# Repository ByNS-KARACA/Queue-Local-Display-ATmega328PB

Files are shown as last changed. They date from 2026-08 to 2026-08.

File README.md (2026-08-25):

# Queue Local Display – ATmega328PB

A modular local queue display controller designed for queue management systems used in hospitals, banks, clinics, public institutions, service counters, and similar environments.

The system is built around the **Microchip ATmega328PB** microcontroller and supports both wired **RS-485 communication** and optional **433 MHz HC-12 wireless communication**.

The display section uses cascaded **HEF4094BT shift registers**, allowing multiple large 7-segment displays to be controlled with only a few MCU pins.

## Features

* Microchip **ATmega328PB**
* 5 V MCU operation
* External **16 MHz crystal**
* 12 V DC input
* **AP63205WU-7** synchronous buck converter for 12 V to 5 V
* **MAX485** RS-485 interface
* Optional **HC-12 433 MHz wireless module**
* Independent hardware UARTs for RS-485 and HC-12
* **HEF4094BT** cascaded display architecture
* **ULN2003A** 5 V to 12 V logic interface
* Static-drive 7-segment display architecture
* 6 × large 56 mm 7-segment display positions
* 2 display positions support optional FJ11001AH alternative displays
* EEPROM-based device addressing
* SET / UP / DOWN configuration buttons
* PWM-capable global display brightness control
* External I²C expansion interface
* Additional GPIO expansion pins
* RS-485 daisy-chain capability
* Optional RS-485 termination
* Designed for continuous **24/7 operation**

## 3D Preview

### Top & Bottom Views

<p align="center">
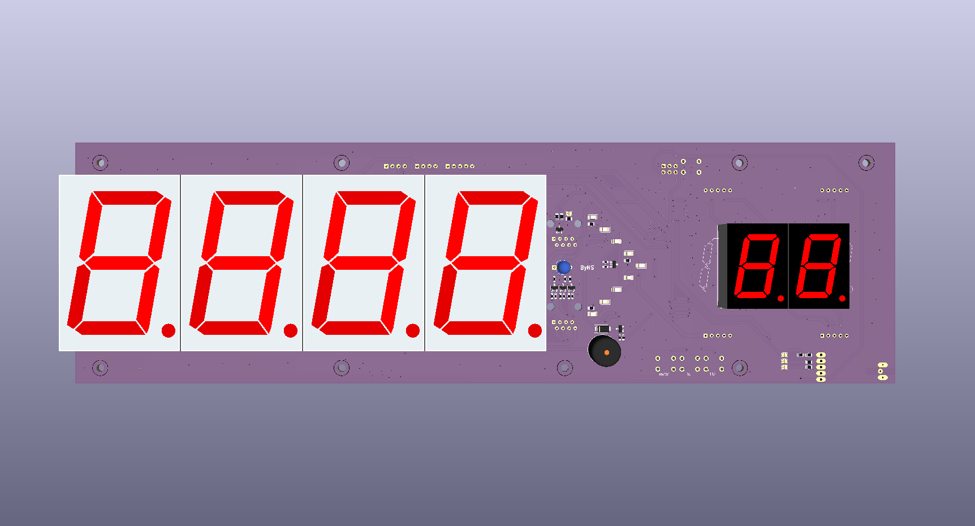
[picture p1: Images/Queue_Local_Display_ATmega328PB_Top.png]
Queue Local Display PCB Top View
  
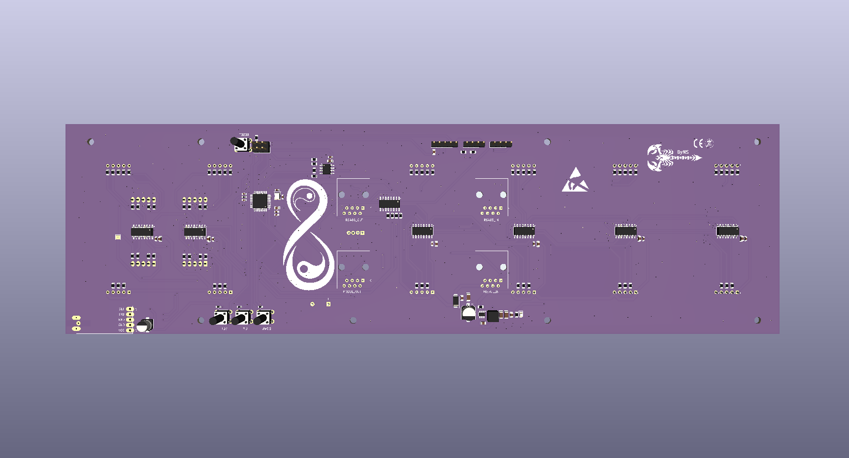
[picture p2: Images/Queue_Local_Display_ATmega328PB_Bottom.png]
Queue Local Display PCB Bottom View
  
</p>

### Angled View

<p align="center">
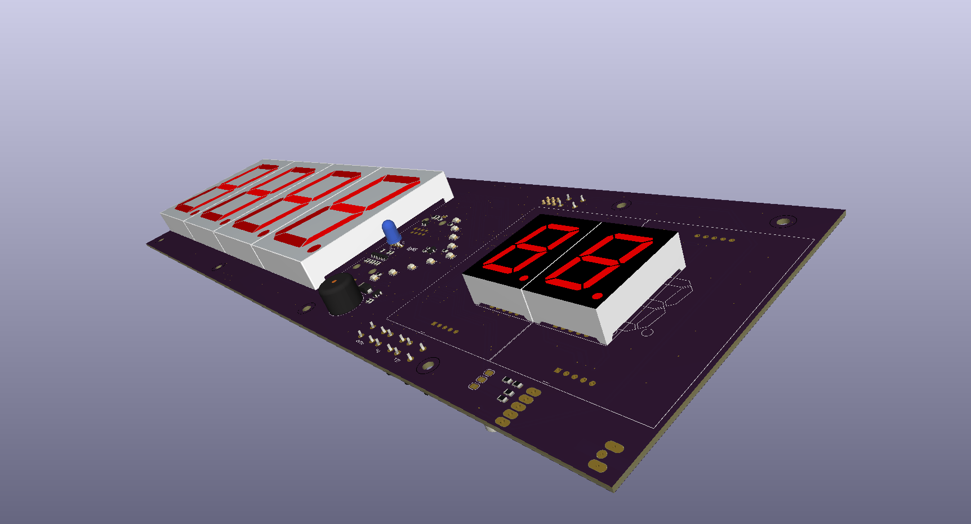
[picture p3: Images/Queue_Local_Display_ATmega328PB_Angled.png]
Queue Local Display PCB Angled View
  
</p>

## Manufacturing Files

Ready-to-manufacture Gerber and drill files are provided for this PCB.

- 📁 [Browse Gerber Files](Hardware/Gerber)
- 📦 [Download Complete Gerber ZIP](Hardware/Gerber/Queue_Local_Display_Atmega328PB_GERBER.zip)
- 🛠️ [KiCad Source Files](Hardware/KiCad)
- 📋 [Bill of Materials (BOM)](Hardware/BOM/Queue_Local_Display_ATmega328PB_BOM.xlsx)
The Gerber package includes the copper, solder mask, silkscreen, solder paste, board outline, plated-hole and non-plated-hole drill files required for PCB fabrication.

### PCB Specifications

| Parameter | Specification |
| --- | --- |
| Layers | 2 |
| PCB Thickness | 1.6 mm |
| Material | FR-4 |
| Copper Thickness | 35 µm / 1 oz |
| Board Size | approximately 340.05 × 100.05 mm |

> **Note:** Always verify the Gerber files and manufacturing parameters with your PCB manufacturer before placing an order.

## Display Configuration

The board uses:

### Main Queue Number

* 4 × **SM412301N**
* 2.3 inch / approximately 56 mm
* Red
* Common Anode
### Optional Alternative Display

Two display positions also support:

- 2 × **FJ11001AH**
- Smaller red 7-segment display
- Optional alternative to SM412301N
- Not populated simultaneously with SM412301N at the same position
### Counter / Desk Number

* 2 × **FJ11001AH**
* Red 7-segment display

Example display format:

```text
+--------------------------------+
|                                |
|       A 1 4 5       0 3        |
|                                |
|       QUEUE        COUNTER      |
+--------------------------------+
```

## Display Driver Architecture

Each 7-segment digit is controlled by its own **HEF4094BT** shift register.

The shift registers are connected in cascade:

```text
ATmega328PB
     |
     | DATA
     v
 HEF4094 #1
     |
    QS2
     v
 HEF4094 #2
     |
    QS2
     v
 HEF4094 #3
     |
    QS2
     v
 HEF4094 #4
     |
    QS2
     v
 HEF4094 #5
     |
    QS2
     v
 HEF4094 #6
```

CLOCK, STROBE and OE lines are shared between all HEF4094 devices.

The HEF4094 devices operate from the **12 V rail**.

A **ULN2003A open-collector interface** with 12 V pull-up resistors is used between the 5 V ATmega328PB and the 12 V HEF4094 control inputs.

## HEF4094 Control Pins

| Function | ATmega328PB |
| --- | --- |
| DATA | D4 |
| OE | D5 |
| CLOCK | D6 |
| STROBE | D7 |

The OE line is connected to a PWM-capable MCU output, allowing global display brightness control.

## RS-485 Interface

The board uses a **MAX485** half-duplex RS-485 transceiver.

| Function  | ATmega328PB |
| --- | --- |
| RS-485 RX | PD0 / RXD0  |
| RS-485 TX | PD1 / TXD0  |
| RE + DE | PB0 / D8 |

The RE and DE pins are connected together and controlled from a single GPIO.

The board is designed for **RS-485 bus / daisy-chain wiring**.

```text
MASTER
   |
LOCAL DISPLAY 01
   |
LOCAL DISPLAY 02
   |
LOCAL DISPLAY 03
   |
LOCAL DISPLAY 04
```

A termination resistor footprint is provided for installations where the display is located at the physical end of the RS-485 bus.

## HC-12 Wireless Interface

An optional **HC-12 433 MHz UART module** can be installed.

ATmega328PB USART1 is used for wireless communication.

| Function  | ATmega328PB |
| --- | --- |
| HC-12 RX  | PB3 / TXD1  |
| HC-12 TX  | PB4 / RXD1  |
| HC-12 SET | PB2 / D10 |

The SET input includes a pull-up resistor to keep the HC-12 in normal operating mode during startup.

## Device Address Configuration

Each local display can be assigned an individual device address.

Three buttons are used:

* **SET**
* **UP**
* **DOWN**

The selected address is stored in the internal EEPROM of the ATmega328PB.

This eliminates the need for DIP switches and simplifies installation and field configuration.

## Power Architecture

```text
12 V DC INPUT
      |
      +--------------------> Displays / HEF4094 / LEDs
      |
      +----> AP63205WU-7
                  |
                  v
                 5 V
                  |
                  +----> ATmega328PB
                  +----> MAX485
                  +----> HC-12
```

The **AP63205WU-7** provides the regulated 5 V logic supply.

The 12 V rail directly supplies the display driver section and external indicators.

## Expansion

Unused ATmega328PB GPIO pins are exposed for future expansion.

Possible future uses include:

* Status LEDs
* Additional buttons
* External sensors
* Relay outputs
* ADC inputs
* Interrupt inputs
* Additional I²C devices
* External indicators

The primary external I²C interface is:

```text
PC4 → SDA0
PC5 → SCL0
```

## Applications

* Hospital queue systems
* Bank queue systems
* Clinic waiting-room displays
* Government service counters
* Pharmacy queue systems
* Restaurant queue systems
* Reception systems
* Service desk displays

## Modular Architecture

The hardware is designed with future modular expansion in mind.

Multiple local display boards can later be combined to create a multi-row **main queue display**, while maintaining a common hardware platform.

## Project Status

**Hardware Design:** Completed
**Firmware:** In Development
**Production Validation:** Pending

This project is currently in the prototype and validation stage.

## Disclaimer

This hardware should be fully tested and validated before use in commercial, medical, industrial, or safety-critical installations.

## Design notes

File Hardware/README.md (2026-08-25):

# Hardware

This directory contains the hardware design files for the Queue Local Display.

## Contents

- KiCad schematic files
- KiCad PCB layout files
- Manufacturing files
- Schematic PDF exports
- Hardware documentation

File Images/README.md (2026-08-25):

# Images

This directory contains visual assets for the Queue Local Display project.

## Contents

- PCB 3D top view
- PCB 3D bottom view
- PCB 3D angled view
- Product and prototype images

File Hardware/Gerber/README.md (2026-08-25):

# Gerber Files

This directory contains the manufacturing output files for the Queue Local Display PCB.

## Contents

- Gerber fabrication files
- Drill files
- Optional compressed Gerber archive

These files can be used directly for PCB manufacturing.

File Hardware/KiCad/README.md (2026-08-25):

# KiCad Design Files

This directory contains the KiCad source files for the Queue Local Display hardware.

## Files

- Schematic design
- PCB layout
- KiCad project file

These files represent the editable hardware source of the project.

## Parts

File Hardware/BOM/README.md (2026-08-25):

# Bill of Materials (BOM)

This directory contains the Bill of Materials for the Queue Local Display PCB.

## Contents

- Component reference designators
- Component values
- Manufacturer part numbers
- Package / footprint information
- Quantity information
- Example supplier / LCSC part numbers where available

## Important Note

Manufacturer and supplier part numbers listed in the BOM are provided primarily as reference components.

Equivalent components with compatible electrical specifications, package dimensions, pinout, voltage/current ratings, tolerance, and temperature ratings may be used when appropriate.

Always verify component compatibility before PCB assembly.

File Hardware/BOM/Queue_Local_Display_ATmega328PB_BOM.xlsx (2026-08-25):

 | Sourced | Placed | References | Value | Footprint | Quantity | Notes
1 |  |  | C4, C6, C8, C15, C16, C18, C20, C22, C24, C26, C28, C30 | 100nF | C_0603_1608Metric | 12
2 |  |  | C5, C17, C19, C21, C23, C25, C27, C29 | 10uF | C_0805_2012Metric | 8
3 |  |  | C7, C9, C12, C14 | 100nF | C_0805_2012Metric | 4
4 |  |  | C1, C2 | 18pF, C0G/NP0 | C_0603_1608Metric | 2
5 |  |  | C10, C11 | 22uF/25V, X7R | C_1206_3216Metric | 2
6 |  |  | C3 | 47uF/35V | CP_Elec_6.3x5.4 | 1
7 |  |  | C13 | 10uF/35V, X7R | C_1206_3216Metric | 1
8 |  |  | C32 | 47uF/16V | CP_Elec_5x5.7 | 1
9 |  |  | R10, R11, R12, R13, R14, R15, R16, R18, R19, R20, R21, R22, R23, R24, R26, R27, R28, R29, R30, R31, R32, R34, R35, R36, R37, R38, R39, R40, R83, R84, R85, R86, R87, R88, R89, R91, R92, R93, R94, R95, R96, R97 | 1.2K %1 | R_0805_2012Metric | 42
10 |  |  | R17, R25, R33, R41, R42, R43, R44, R45, R46, R47, R48, R49, R50, R51, R52, R53, R54, R55, R56, R57, R90, R98 | 2.7K %1 | R_0805_2012Metric | 22
11 |  |  | R69, R70, R71, R72, R75, R78, R81, R103 | 10K | R_0603_1608Metric | 8
12 |  |  | R2, R3, R4, R5, R6, R7 | 4.7K | R_0805_2012Metric | 6
13 |  |  | R73, R74, R77, R80, R102 | 1K | R_0603_1608Metric | 5
14 |  |  | R1, R60, R61, R68 | 10K | R_0805_2012Metric | 4
15 |  |  | R65, R66, R67 | 33 | R_0805_2012Metric | 3
16 |  |  | R76, R79, R82 | 220 | R_0603_1608Metric | 3
17 |  |  | R99, R100, R101 | 470 | R_0805_2012Metric | 3
18 |  |  | R8, R9 | 1K | R_0805_2012Metric | 2
19 |  |  | R58, R59 | 220 | R_0805_2012Metric | 2
20 |  |  | R62, R63 | 10 | R_0805_2012Metric | 2
21 |  |  | R64 | 120 | R_0805_2012Metric | 1
22 |  |  | L1 | 10uH | L_0603_1608Metric | 1
23 | C341032 |  | L2 | 4.7uH 3A 5*5mm , YNR5040-4R7M | L_Chilisin_BWVS00505040 | 1
24 |  | GREEN_LED | D5, D7, D8, D9, D10, D11, D12, D13, D14 | GREEN_LED | LED_1206_3216Metric | 9
25 |  |  | D1 | RED_LED | LED_0805_2012Metric | 1
26 |  |  | D2 | SS34 | D_SMA | 1
27 |  |  | D3 | SM712_SOT23 | SOT-23 | 1
28 |  |  | D4 | M7F | D_SMA | 1
29 | XL-B504RGBC | CA_RGB_LED | D6 | LED_BAGR | LED_D5.0mm-4_RGB_Wide_Pins | 1
30 | C7868 |  | U2, U5, U6, U7, U8, U9 | HEF4094BT,653 | SOIC-16_3.9x9.9mm_P1.27mm | 6
31 | C164872 |  | U10, U11, U12, U13, U15, U16 | SM412301N | SA15-11xxx | 6 | Default display option. Six SM412301N displays are listed. Two of these display positions may alternatively use FJ11001AH.
32 | C461612 | ATMEGA328PB | U1 | ATmega328PB-A | TQFP-32_7x7mm_P0.8mm | 1
33 | C5181464 |  | U3 | ULN2003A | SOIC-16_3.9x9.9mm_P1.27mm | 1
34 |  |  | U4 | AP63205WU-7 | TSOT-23-6 | 1
35 |  |  | U14 | MAX485ED | SOIC-8_3.9x4.9mm_P1.27mm | 1
36 | C12668 |  | Y1 | 16Mhz, 12pF | Crystal_SMD_3225-4Pin_3.2x2.5mm | 1
37 |  |  | SW1 | SW_Push | SW_PUSH_6mm_H13mm | 1
38 |  |  | SW2 | UP | SW_PUSH_6mm_H13mm | 1
39 |  |  | SW3 | DOWN | SW_PUSH_6mm_H13mm | 1
40 |  |  | SW4 | SET | SW_PUSH_6mm_H13mm | 1
41 |  |  | Q1, Q2, Q3, Q4, Q5 | MMBT2222A | SOT-23 | 5
42 | C10687 |  | AFF1, AFF2 | FJ11001AH | 7SegmentLED_LTS6760_LTS6780 | 2 | OPTIONAL ALTERNATIVE / DNP by default. FJ11001AH can replace two SM412301N display positions. Do not populate both display types at the same position.
43 |  |  | BZ1 | Buzzer | Buzzer_12x9.5RM7.6 | 1
44 |  |  | M1 | HC-12 | MA05-1 | 1
45 |  |  | TP1 | TestPoint | TestPoint_Pad_2.0x2.0mm | 1
46 |  |  | J2, J4, J7, J8 | RJ45 | RJ45_Amphenol_54602-x08_Horizontal | 4
47 |  |  | J1 | AVR-ISP | PinHeader_2x03_P2.54mm_Vertical | 1
48 |  |  | J3 | UART-SERIAL | PinHeader_1x05_P2.54mm_Vertical | 1
49 |  |  | J5 | I2C | PinHeader_1x04_P2.54mm_Vertical | 1
50 |  |  | J6 | NULL_PIN | PinHeader_1x04_P2.54mm_Vertical | 1
 |  | NOTE-1 | Orange-colored companents will be supplied but will not be mounted on the board.
 |  | NOTE-2 | Red-colored companents will not be supplied and will not be mounted on the board.
 |  | NOTE-3 | **COMPONENT SELECTION NOTE** The manufacturer part numbers listed in this BOM are provided for reference only and do not mandate the use of those exact components. The manufacturer may select suitable and readily available equivalent components, provided that they fully meet or exceed the specified electrical, mechanical, functional, quality, and reliability requirements. Any proposed alternative must be compatible in terms of package, footprint, pinout, operating ratings, temperature range, and applicable certifications. All substitutions must be submitted for approval before procurement or production.
 |  | NOTE-4 | **DISPLAY OPTION NOTE** The standard configuration uses 6 × SM412301N displays. For two display positions, FJ11001AH may be used as an optional alternative instead of SM412301N. These alternatives are mutually exclusive at the same position; do not populate both display types simultaneously.

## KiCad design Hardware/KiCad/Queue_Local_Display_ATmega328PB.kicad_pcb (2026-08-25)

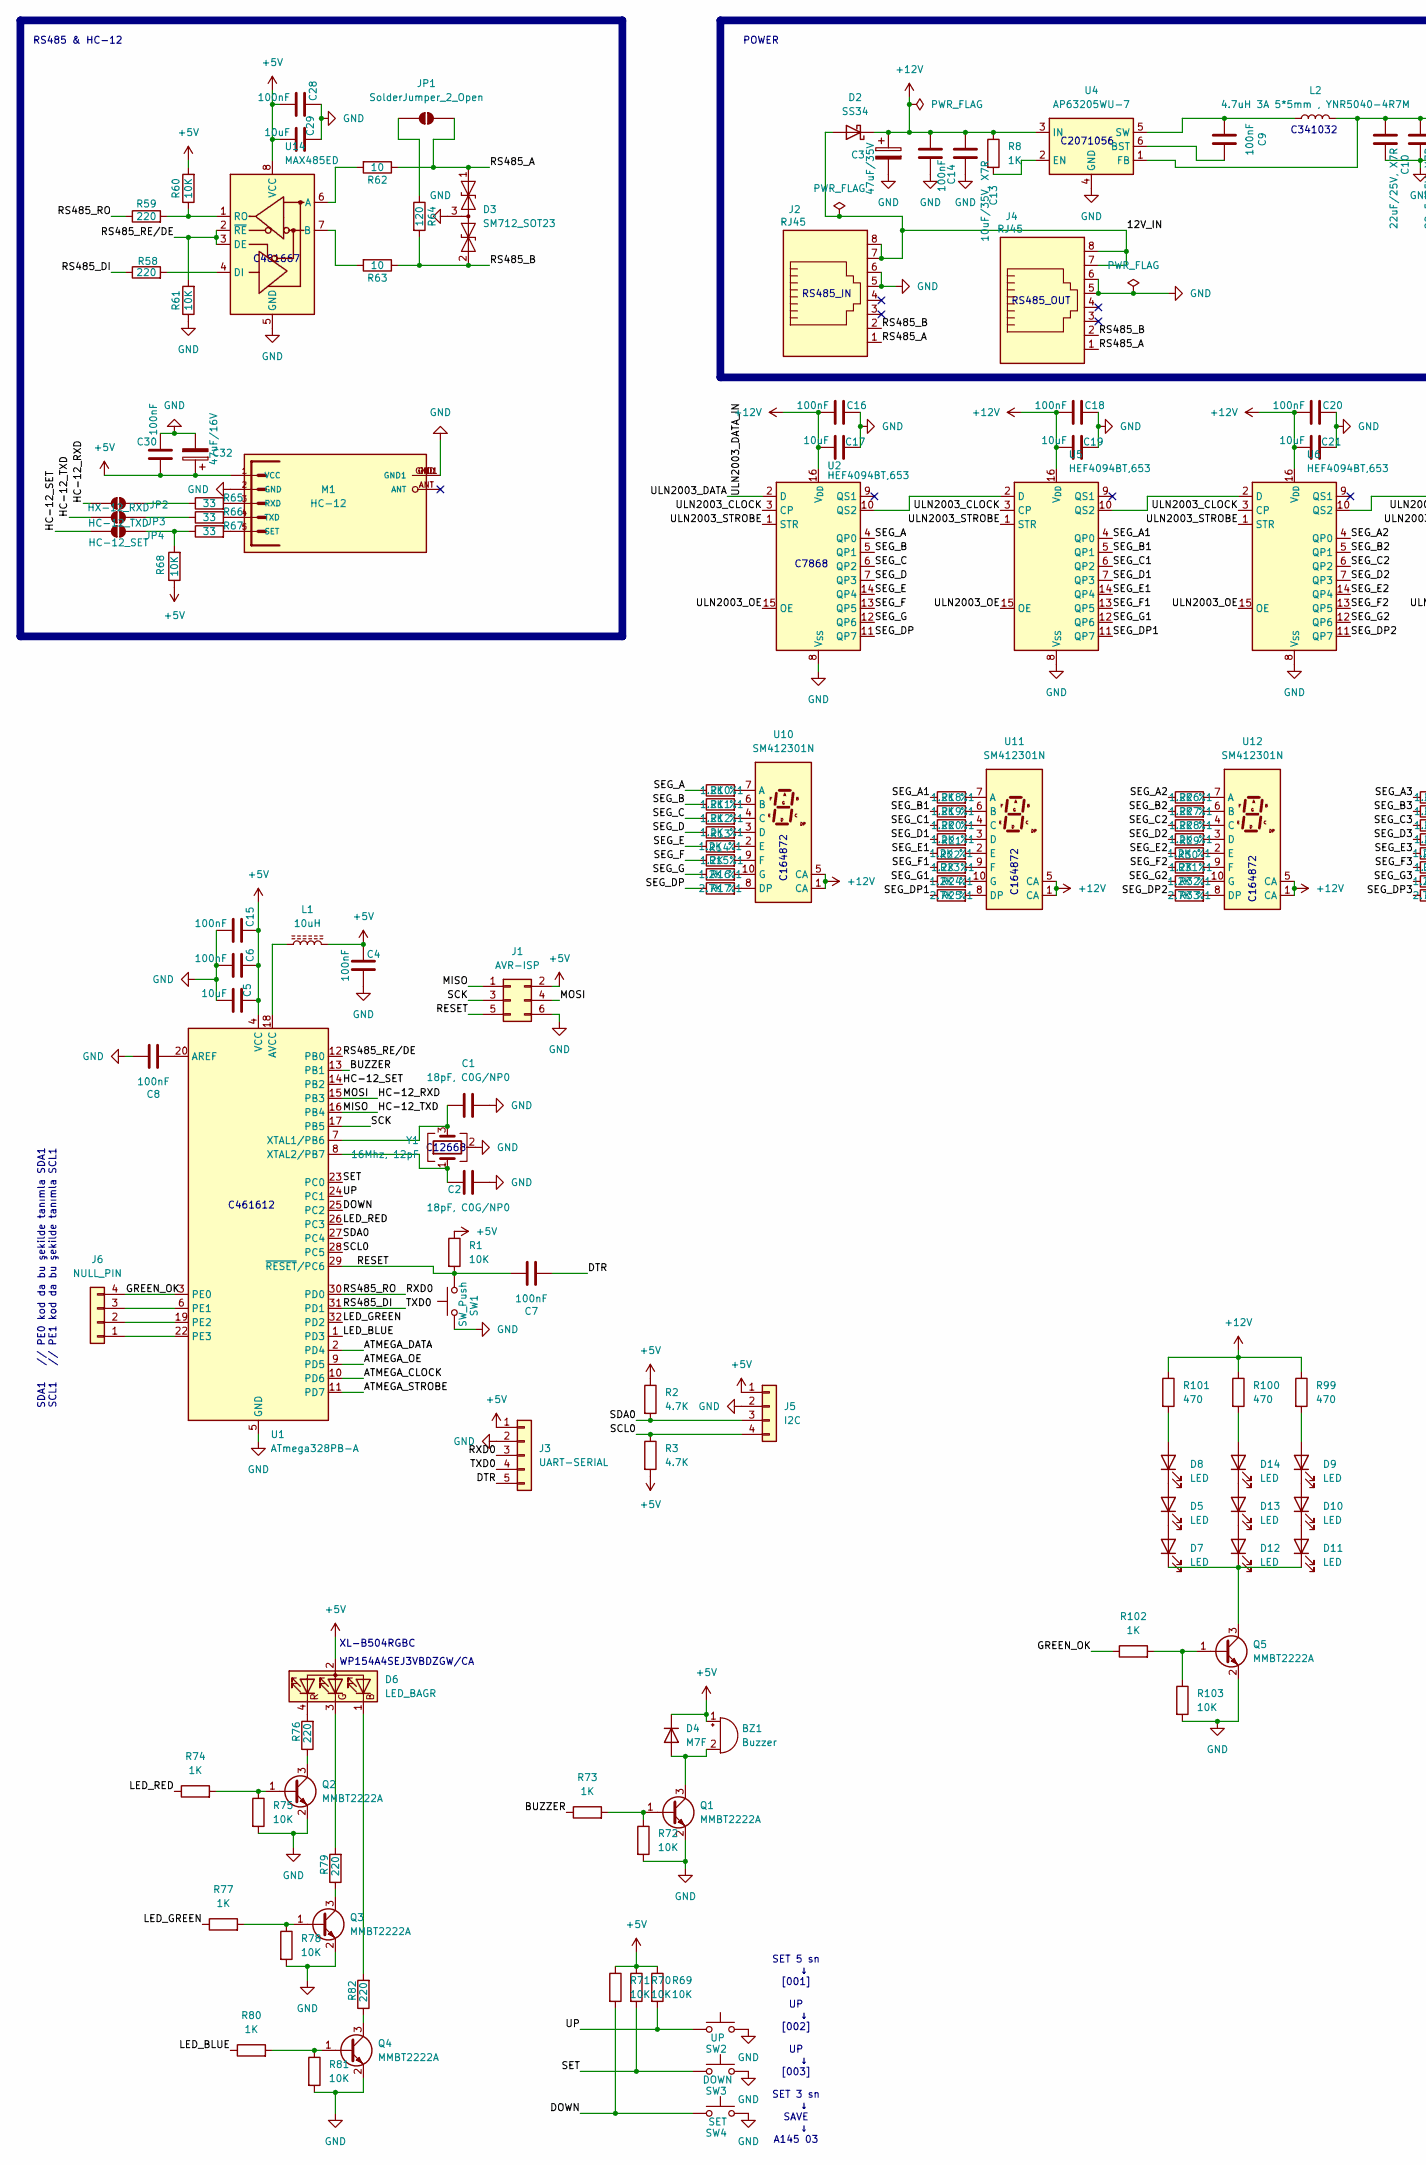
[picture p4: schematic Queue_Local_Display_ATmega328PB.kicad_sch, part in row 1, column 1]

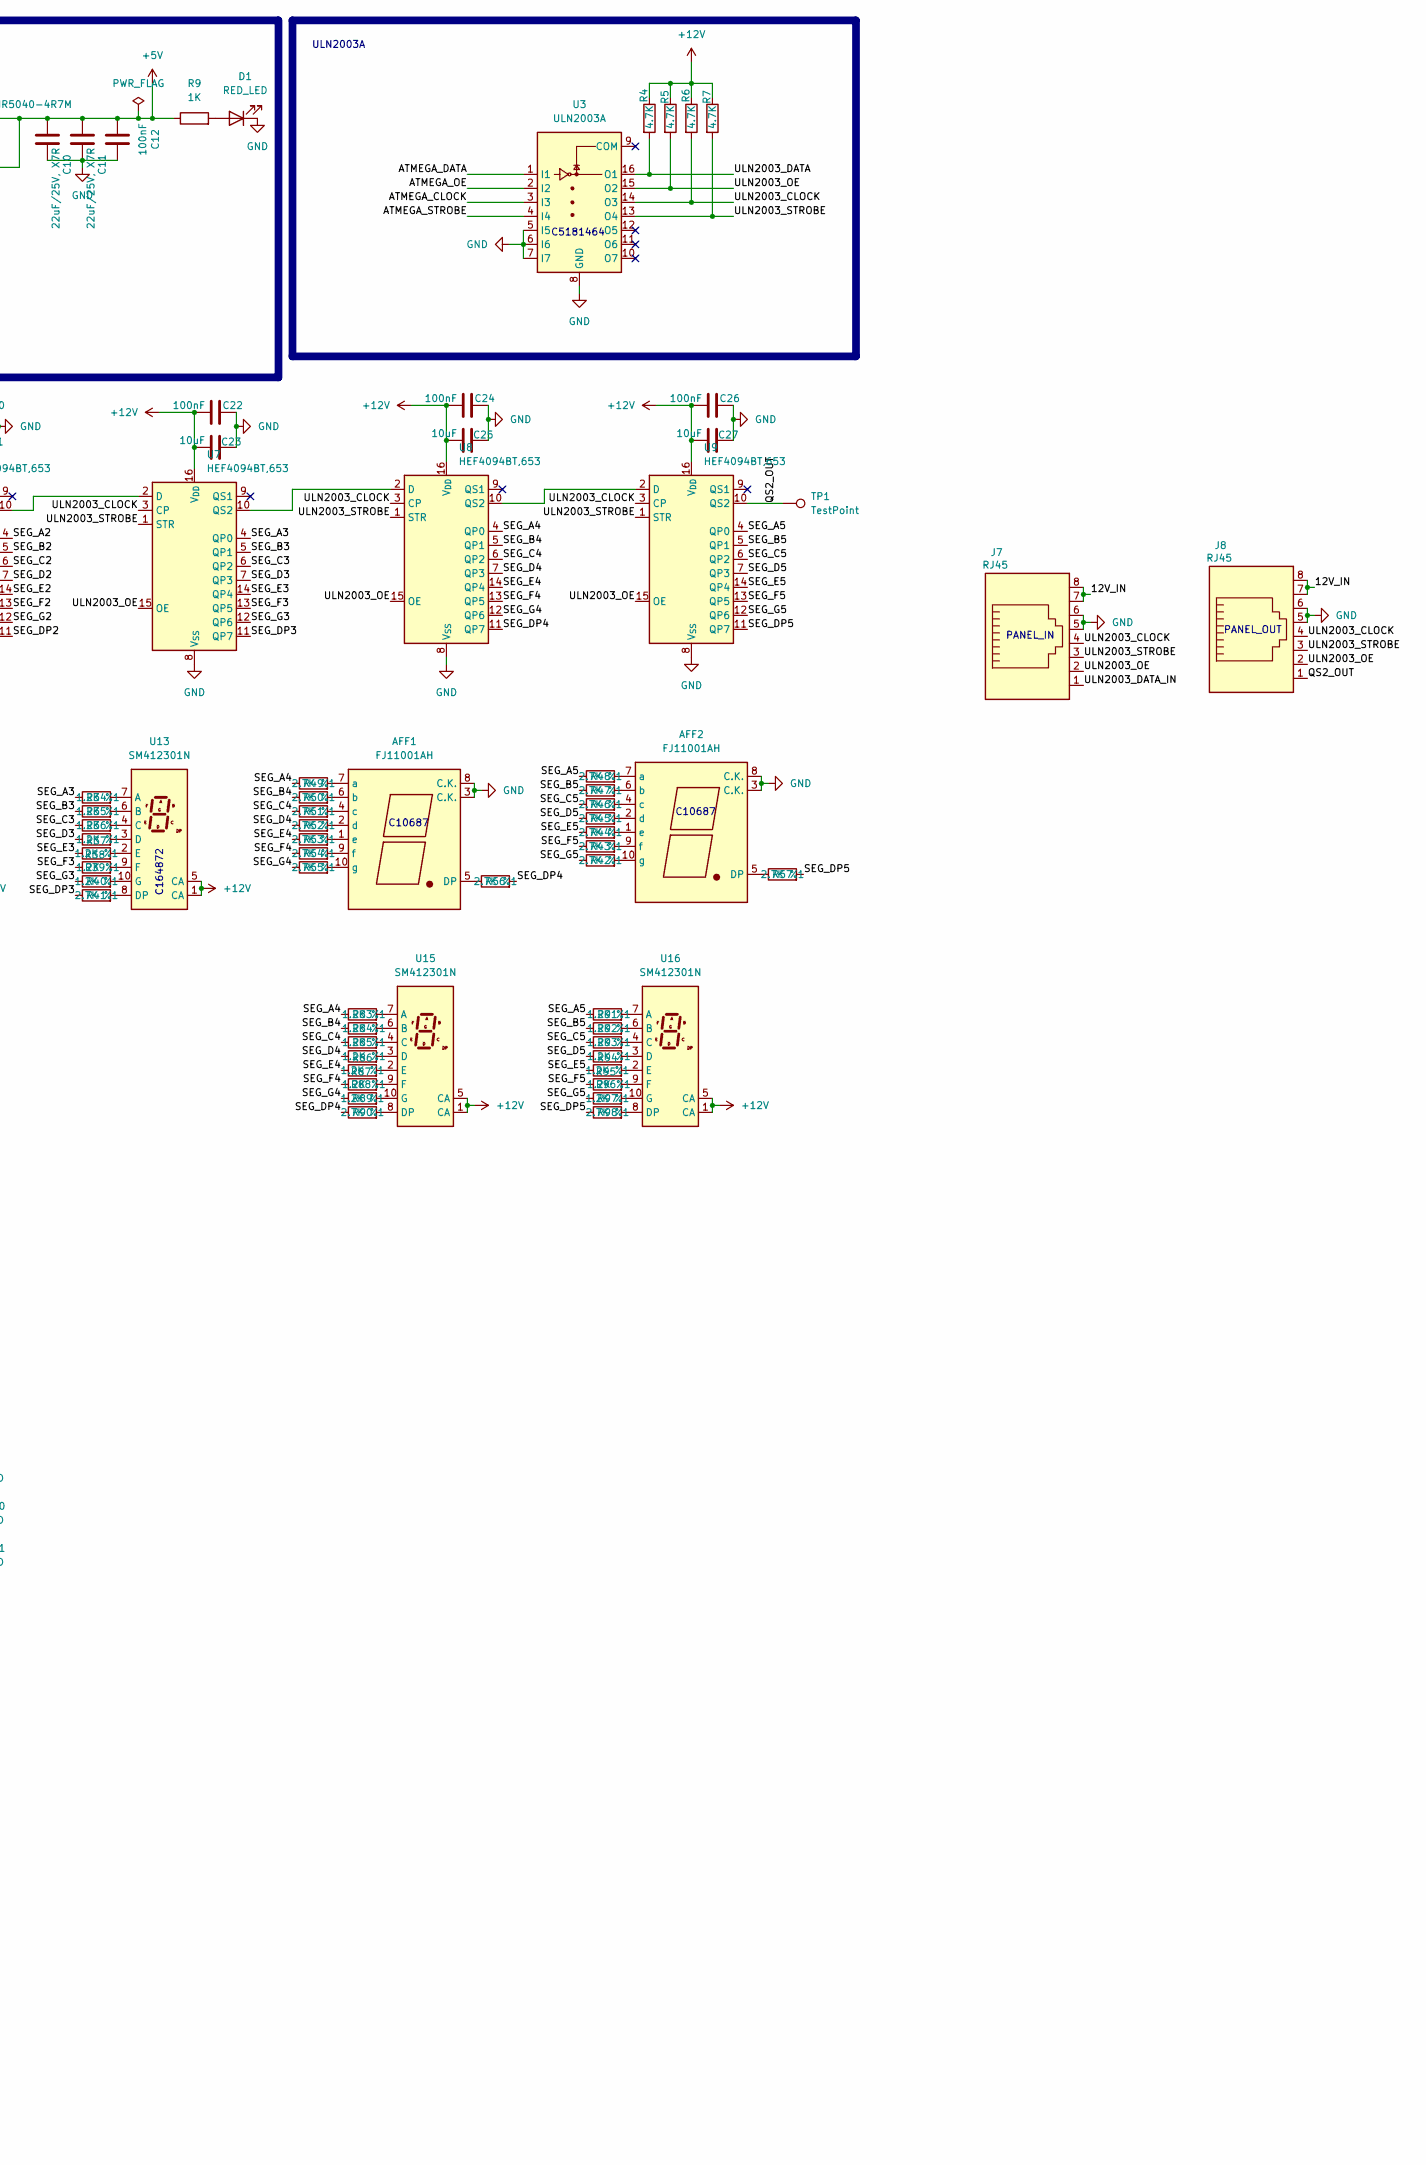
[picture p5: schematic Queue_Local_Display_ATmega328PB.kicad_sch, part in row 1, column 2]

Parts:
AFF1, AFF2: FJ11001AH; 7SegmentLED_LTS6760_LTS6780
BZ1: Buzzer; Buzzer_12x9.5RM7.6
C1, C2: 18pF, C0G/NP0; C_0603_1608Metric
C3: 47uF/35V; CP_Elec_6.3x5.4
C4, C6, C8, C15, C16, C18, C20, C22, C24, C26, C28, C30: 100nF; C_0603_1608Metric
C5, C17, C19, C21, C23, C25, C27, C29: 10uF; C_0805_2012Metric
C7, C9, C12, C14: 100nF; C_0805_2012Metric
C10, C11: 22uF/25V, X7R; C_1206_3216Metric
C13: 10uF/35V, X7R; C_1206_3216Metric
C32: 47uF/16V; CP_Elec_5x5.7
D1: RED_LED; LED_0805_2012Metric
D2: SS34; D_SMA
D3: SM712_SOT23; SOT-23
D4: M7F; D_SMA
D5, D7, D8, D9, D10, D11, D12, D13, D14: LED; LED_1206_3216Metric
D6: LED_BAGR; LED_D5.0mm-4_RGB_Wide_Pins
J1: AVR-ISP; PinHeader_2x03_P2.54mm_Vertical
J2, J4, J7, J8: RJ45; RJ45_Amphenol_54602-x08_Horizontal
J3: UART-SERIAL; PinHeader_1x05_P2.54mm_Vertical
J5: I2C; PinHeader_1x04_P2.54mm_Vertical
J6: NULL_PIN; PinHeader_1x04_P2.54mm_Vertical
JP1: SolderJumper_2_Open; SolderJumper-2_P1.3mm_Open_RoundedPad1.0x1.5mm
JP2: HX-12_RXD; SolderJumper-2_P1.3mm_Open_RoundedPad1.0x1.5mm
JP3: HC-12_TXD; SolderJumper-2_P1.3mm_Open_RoundedPad1.0x1.5mm
JP4: HC-12_SET; SolderJumper-2_P1.3mm_Open_RoundedPad1.0x1.5mm
L1: 10uH; L_0603_1608Metric
L2: 4.7uH 3A 5*5mm , YNR5040-4R7M; L_Chilisin_BWVS00505040
M1: HC-12; MA05-1
Q1, Q2, Q3, Q4, Q5: MMBT2222A; SOT-23
R1, R60, R61, R68: 10K; R_0805_2012Metric
R2, R3, R4, R5, R6, R7: 4.7K; R_0805_2012Metric
R8, R9: 1K; R_0805_2012Metric
R10, R11, R12, R13, R14, R15, R16, R18, R19, R20, R21, R22, R23, R24, R26, R27, R28, R29, R30, R31, R32, R34, R35, R36, R37, R38, R39, R40, R83, R84, R85, R86, R87, R88, R89, R91, R92, R93, R94, R95, R96, R97: 1.2K %1; R_0805_2012Metric
R17, R25, R33, R41, R42, R43, R44, R45, R46, R47, R48, R49, R50, R51, R52, R53, R54, R55, R56, R57, R90, R98: 2.7K %1; R_0805_2012Metric
R58, R59: 220; R_0805_2012Metric
R62, R63: 10; R_0805_2012Metric
R64: 120; R_0805_2012Metric
R65, R66, R67: 33; R_0805_2012Metric
R69, R70, R71, R72, R75, R78, R81, R103: 10K; R_0603_1608Metric
R73, R74, R77, R80, R102: 1K; R_0603_1608Metric
R76, R79, R82: 220; R_0603_1608Metric
R99, R100, R101: 470; R_0805_2012Metric
SW1: SW_Push; SW_PUSH_6mm_H13mm
SW2: UP; SW_PUSH_6mm_H13mm
SW3: DOWN; SW_PUSH_6mm_H13mm
SW4: SET; SW_PUSH_6mm_H13mm
TP1: TestPoint; TestPoint_Pad_2.0x2.0mm
U1: ATmega328PB-A; TQFP-32_7x7mm_P0.8mm
U2, U5, U6, U7, U8, U9: HEF4094BT,653; SOIC-16_3.9x9.9mm_P1.27mm
U3: ULN2003A; SOIC-16_3.9x9.9mm_P1.27mm
U4: AP63205WU-7; TSOT-23-6
U10, U11, U12, U13, U15, U16: SM412301N; SA15-11xxx
U14: MAX485ED; SOIC-8_3.9x4.9mm_P1.27mm
Y1: 16Mhz, 12pF; Crystal_SMD_3225-4Pin_3.2x2.5mm

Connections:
+5V: BZ1.1 (+), C4.1, C5.2, C6.2, C10.1, C11.1, C12.1, C15.2, C28.1, C29.1, C30.1, C32.1, D4.1 (K), D6.2 (A), J1.2, J3.1, J5.1, L1.2, L2.2, M1.1 (VCC), R1.1, R2.1, R3.2, R9.1, R60.2, R68.1, R69.1, R70.1, R71.1, U1.4 (VCC), U4.1 (FB), U14.8 (VCC)
+12V: C3.1, C13.1, C14.1, C16.1, C17.1, C18.1, C19.1, C20.1, C21.1, C22.1, C23.1, C24.1, C25.1, C26.1, C27.1, D2.1 (K), R4.1, R5.1, R6.1, R7.1, R8.1, R99.1, R100.1, R101.1, U2.16 (V_{DD}), U4.3 (IN), U5.16 (V_{DD}), U6.16 (V_{DD}), U7.16 (V_{DD}), U8.16 (V_{DD}), U9.16 (V_{DD}), U10.1 (CA), U10.5 (CA), U11.1 (CA), U11.5 (CA), U12.1 (CA), U12.5 (CA), U13.1 (CA), U13.5 (CA), U15.1 (CA), U15.5 (CA), U16.1 (CA), U16.5 (CA)
/12V_IN: D2.2 (A), J2.7, J2.8, J4.7, J4.8, J7.7, J7.8, J8.7, J8.8
/ATMEGA_CLOCK: U1.10 (PD6), U3.3 (I3)
/ATMEGA_DATA: U1.2 (PD4), U3.1 (I1)
/ATMEGA_OE: U1.9 (PD5), U3.2 (I2)
/ATMEGA_STROBE: U1.11 (PD7), U3.4 (I4)
/BUZZER: R73.1, U1.13 (PB1)
/DTR: C7.1, J3.5
/GREEN_OK: J6.4, R102.1, U1.3 (PE0)
/HC-12_RXD: J1.4, JP2.1 (A), U1.15 (PB3)
/HC-12_SET: JP4.1 (A), U1.14 (PB2)
/HC-12_TXD: J1.1, JP3.1 (A), U1.16 (PB4)
/LED_BLUE: R80.1, U1.1 (PD3)
/LED_GREEN: R77.1, U1.32 (PD2)
/LED_RED: R74.1, U1.26 (PC3)
/QS2_OUT: J8.1, TP1.1 (1_1), U9.10 (QS2)
/RESET: C7.2, J1.5, R1.2, SW1.2, U1.29 (~RESET/PC6)
/RS485_A: D3.1 (A1), J2.1, J4.1, JP1.2 (B), R62.1
/RS485_B: D3.2 (A2), J2.2, J4.2, R63.1, R64.2
/RS485_DI: J3.4, R58.1, U1.31 (PD1)
/RS485_RE/DE: R61.2, U1.12 (PB0), U14.2 (~RE), U14.3 (DE)
/RS485_RO: J3.3, R59.1, U1.30 (PD0)
/SCK: J1.3, U1.17 (PB5)
/SCL0: J5.4, R3.1, U1.28 (PC5)
/SDA0: J5.3, R2.2, U1.27 (PC4)
/SEG_A: R10.1, U2.4 (QP0)
/SEG_A1: R18.1, U5.4 (QP0)
/SEG_A2: R26.1, U6.4 (QP0)
/SEG_A3: R34.1, U7.4 (QP0)
/SEG_A4: R49.1, R83.1, U8.4 (QP0)
/SEG_A5: R48.1, R91.1, U9.4 (QP0)
/SEG_B: R11.1, U2.5 (QP1)
/SEG_B1: R19.1, U5.5 (QP1)
/SEG_B2: R27.1, U6.5 (QP1)
/SEG_B3: R35.1, U7.5 (QP1)
/SEG_B4: R50.1, R84.1, U8.5 (QP1)
/SEG_B5: R47.1, R92.1, U9.5 (QP1)
/SEG_C: R12.1, U2.6 (QP2)
/SEG_C1: R20.1, U5.6 (QP2)
/SEG_C2: R28.1, U6.6 (QP2)
/SEG_C3: R36.1, U7.6 (QP2)
/SEG_C4: R51.1, R85.1, U8.6 (QP2)
/SEG_C5: R46.1, R93.1, U9.6 (QP2)
/SEG_D: R13.1, U2.7 (QP3)
/SEG_D1: R21.1, U5.7 (QP3)
/SEG_D2: R29.1, U6.7 (QP3)
/SEG_D3: R37.1, U7.7 (QP3)
/SEG_D4: R52.1, R86.1, U8.7 (QP3)
/SEG_D5: R45.1, R94.1, U9.7 (QP3)
/SEG_DP: R17.1, U2.11 (QP7)
/SEG_DP1: R25.1, U5.11 (QP7)
/SEG_DP2: R33.1, U6.11 (QP7)
/SEG_DP3: R41.1, U7.11 (QP7)
/SEG_DP4: R56.2, R90.1, U8.11 (QP7)
/SEG_DP5: R57.2, R98.1, U9.11 (QP7)
/SEG_E: R14.1, U2.14 (QP4)
/SEG_E1: R22.1, U5.14 (QP4)
/SEG_E2: R30.1, U6.14 (QP4)
/SEG_E3: R38.1, U7.14 (QP4)
/SEG_E4: R53.1, R87.1, U8.14 (QP4)
/SEG_E5: R44.1, R95.1, U9.14 (QP4)
/SEG_F: R15.1, U2.13 (QP5)
/SEG_F1: R23.1, U5.13 (QP5)
/SEG_F2: R31.1, U6.13 (QP5)
/SEG_F3: R39.1, U7.13 (QP5)
/SEG_F4: R54.1, R88.1, U8.13 (QP5)
/SEG_F5: R43.1, R96.1, U9.13 (QP5)
/SEG_G: R16.1, U2.12 (QP6)
/SEG_G1: R24.1, U5.12 (QP6)
/SEG_G2: R32.1, U6.12 (QP6)
/SEG_G3: R40.1, U7.12 (QP6)
/SEG_G4: R55.1, R89.1, U8.12 (QP6)
/SEG_G5: R42.1, R97.1, U9.12 (QP6)
/ULN2003_CLOCK: J7.4, J8.4, R6.2, U2.3 (CP), U3.14 (O3), U5.3 (CP), U6.3 (CP), U7.3 (CP), U8.3 (CP), U9.3 (CP)
/ULN2003_DATA: J7.1, R4.2, U2.2 (D), U3.16 (O1)
/ULN2003_OE: J7.2, J8.2, R5.2, U2.15 (OE), U3.15 (O2), U5.15 (OE), U6.15 (OE), U7.15 (OE), U8.15 (OE), U9.15 (OE)
/ULN2003_STROBE: J7.3, J8.3, R7.2, U2.1 (STR), U3.13 (O4), U5.1 (STR), U6.1 (STR), U7.1 (STR), U8.1 (STR), U9.1 (STR)
/UP: R69.2, SW2.1, U1.24 (PC1)
GND: AFF1.3 (C.K.), AFF1.8 (C.K.), AFF2.3 (C.K.), AFF2.8 (C.K.), C1.2, C2.1, C3.2, C4.2, C5.1, C6.1, C8.2, C10.2, C11.2, C12.2, C13.2, C14.2, C15.1, C16.2, C17.2, C18.2, C19.2, C20.2, C21.2, C22.2, C23.2, C24.2, C25.2, C26.2, C27.2, C28.2, C29.2, C30.2, C32.2, D1.1 (K), D3.3 (common), J1.6, J2.5, J2.6, J3.2, J4.5, J4.6, J5.2, J7.5, J7.6, J8.5, J8.6, M1.2 (GND), M1.GND (GND1), M1.GND1, Q1.2 (E), Q2.2 (E), Q3.2 (E), Q4.2 (E), Q5.2 (E), R61.1, R72.2, R75.2, R78.2, R81.2, R103.2, SW1.1, SW2.2, SW3.2, SW4.2, U1.5 (GND), U1.21 (GND), U2.8 (V_{SS}), U3.5 (I5), U3.6 (I6), U3.7 (I7), U3.8 (GND), U4.4 (GND), U5.8 (V_{SS}), U6.8 (V_{SS}), U7.8 (V_{SS}), U8.8 (V_{SS}), U9.8 (V_{SS}), U14.5 (GND), Y1.2 (G), Y1.4 (G)
unnamed: AFF1.5 (DP), R56.1
unnamed: AFF1.7 (a), R49.2
unnamed: AFF1.6 (b), R50.2
unnamed: AFF1.4 (c), R51.2
unnamed: AFF1.2 (d), R52.2
unnamed: AFF1.1 (e), R53.2
unnamed: AFF1.9 (f), R54.2
unnamed: AFF1.10 (g), R55.2
unnamed: AFF2.5 (DP), R57.1
unnamed: AFF2.7 (a), R48.2
unnamed: AFF2.6 (b), R47.2
unnamed: AFF2.4 (c), R46.2
unnamed: AFF2.2 (d), R45.2
unnamed: AFF2.1 (e), R44.2
unnamed: AFF2.9 (f), R43.2
unnamed: AFF2.10 (g), R42.2
unnamed: BZ1.2 (-), D4.2 (A), Q1.3 (C)
unnamed: D1.2 (A), R9.2
unnamed: D5.2 (A), D8.1 (K)
unnamed: D5.1 (K), D7.2 (A)
unnamed: D6.1 (BK), R82.2
unnamed: D6.3 (GK), R79.2
unnamed: D6.4 (RK), R76.2
unnamed: D8.2 (A), R101.2
unnamed: D9.2 (A), R99.2
unnamed: D9.1 (K), D10.2 (A)
unnamed: D10.1 (K), D11.2 (A)
unnamed: D7.1 (K), D11.1 (K), D12.1 (K), Q5.3 (C)
unnamed: D12.2 (A), D13.1 (K)
unnamed: D13.2 (A), D14.1 (K)
unnamed: D14.2 (A), R100.2
unnamed: J6.1, U1.22 (PE3)
unnamed: J6.2, U1.19 (PE2)
unnamed: J6.3, U1.6 (PE1)
unnamed: JP1.1 (A), R64.1
unnamed: JP2.2 (B), R65.1
unnamed: JP3.2 (B), R66.1
unnamed: JP4.2 (B), R67.1, R68.2
unnamed: M1.3 (RXD), R65.2
unnamed: M1.5 (SET), R67.2
unnamed: M1.4 (TXD), R66.2
unnamed: Q1.1 (B), R72.1, R73.2
unnamed: Q2.1 (B), R74.2, R75.1
unnamed: Q2.3 (C), R76.1
unnamed: Q3.1 (B), R77.2, R78.1
unnamed: Q3.3 (C), R79.1
unnamed: Q4.1 (B), R80.2, R81.1
unnamed: Q4.3 (C), R82.1
unnamed: Q5.1 (B), R102.2, R103.1
unnamed: C8.1, U1.20 (AREF)
unnamed: L1.1, U1.18 (AVCC)
unnamed: C1.1, U1.7 (XTAL1/PB6), Y1.3
unnamed: C2.2, U1.8 (XTAL2/PB7), Y1.1
unnamed: U2.10 (QS2), U5.2 (D)
unnamed: C9.2, U4.6 (BST)
unnamed: R8.2, U4.2 (EN)
unnamed: C9.1, L2.1, U4.5 (SW)
unnamed: U5.10 (QS2), U6.2 (D)
unnamed: U6.10 (QS2), U7.2 (D)
unnamed: U7.10 (QS2), U8.2 (D)
unnamed: U8.10 (QS2), U9.2 (D)
unnamed: R10.2, U10.7 (A)
unnamed: R11.2, U10.6 (B)
unnamed: R12.2, U10.4 (C)
unnamed: R13.2, U10.3 (D)
unnamed: R17.2, U10.8 (DP)
unnamed: R14.2, U10.2 (E)
unnamed: R15.2, U10.9 (F)
unnamed: R16.2, U10.10 (G)
unnamed: R18.2, U11.7 (A)
unnamed: R19.2, U11.6 (B)
unnamed: R20.2, U11.4 (C)
unnamed: R21.2, U11.3 (D)
unnamed: R25.2, U11.8 (DP)
unnamed: R22.2, U11.2 (E)
unnamed: R23.2, U11.9 (F)
unnamed: R24.2, U11.10 (G)
unnamed: R26.2, U12.7 (A)
unnamed: R27.2, U12.6 (B)
unnamed: R28.2, U12.4 (C)
unnamed: R29.2, U12.3 (D)
unnamed: R33.2, U12.8 (DP)
unnamed: R30.2, U12.2 (E)
unnamed: R31.2, U12.9 (F)
unnamed: R32.2, U12.10 (G)
unnamed: R34.2, U13.7 (A)
unnamed: R35.2, U13.6 (B)
unnamed: R36.2, U13.4 (C)
unnamed: R37.2, U13.3 (D)
unnamed: R41.2, U13.8 (DP)
unnamed: R38.2, U13.2 (E)
unnamed: R39.2, U13.9 (F)
unnamed: R40.2, U13.10 (G)
unnamed: R62.2, U14.6 (A)
unnamed: R63.2, U14.7 (B)
unnamed: R58.2, U14.4 (DI)
unnamed: R59.2, R60.1, U14.1 (RO)
unnamed: R83.2, U15.7 (A)
unnamed: R84.2, U15.6 (B)
unnamed: R85.2, U15.4 (C)
unnamed: R86.2, U15.3 (D)
unnamed: R90.2, U15.8 (DP)
unnamed: R87.2, U15.2 (E)
unnamed: R88.2, U15.9 (F)
unnamed: R89.2, U15.10 (G)
unnamed: R91.2, U16.7 (A)
unnamed: R92.2, U16.6 (B)
unnamed: R93.2, U16.4 (C)
unnamed: R94.2, U16.3 (D)
unnamed: R98.2, U16.8 (DP)
unnamed: R95.2, U16.2 (E)
unnamed: R96.2, U16.9 (F)
unnamed: R97.2, U16.10 (G)

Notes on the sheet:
XL-B504RGBC
ULN2003A
C341032
RS485_IN
C164872
RS485 & HC-12
C5181464
C481667
C461612
SET 5 sn ↓ [001] UP ↓ [002] UP ↓ [003] SET 3 sn ↓ SAVE ↓ A145 03
C12668
RS485_OUT
POWER
C10687
SDA1 // PE0 kod da bu şekilde tanımla SDA1 SCL1 // PE1 kod da bu şekilde tanımla SCL1
C7868
PANEL_OUT
C2071056
PANEL_IN
WP154A4SEJ3VBDZGW/CA

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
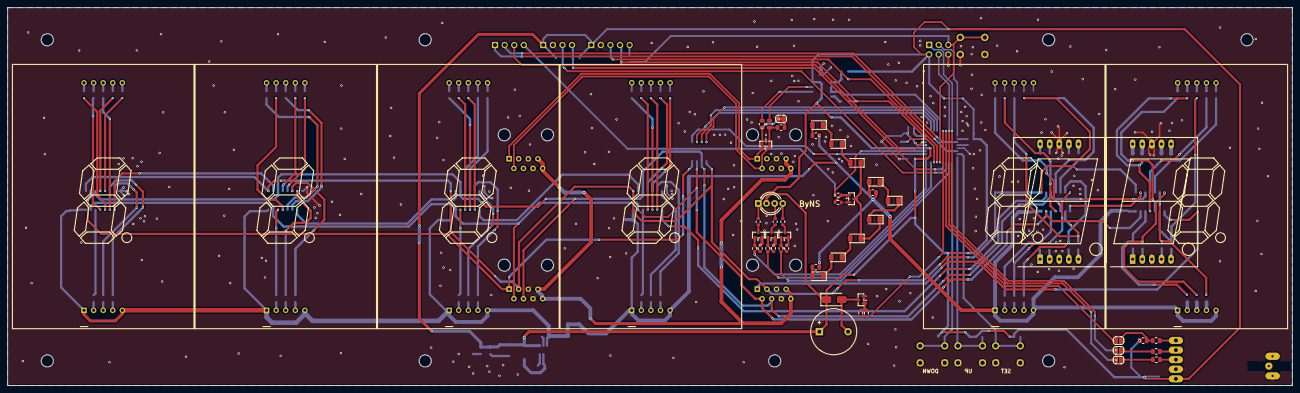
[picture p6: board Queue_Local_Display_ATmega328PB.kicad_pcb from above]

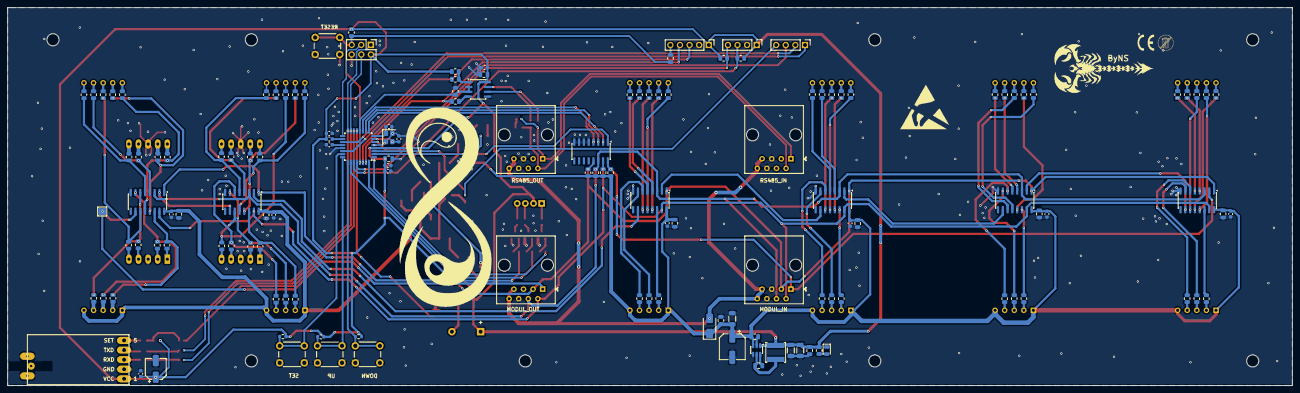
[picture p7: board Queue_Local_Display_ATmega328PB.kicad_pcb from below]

Board: 2 copper layers, 340.0 x 100.0 mm, 193 parts (140 on the bottom side), 195 nets.

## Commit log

2026-08-25 Add KiCad hardware directory
    Added README.md to document KiCad design files for hardware.
2026-08-25 Queue Local Display – ATmega328PB
2026-08-25 Add KiCad design files
    [Queue_Local_Display_ATmega328PB.kicad_pcb, Queue_Local_Display_ATmega328PB.kicad_sch]
2026-08-25 Add PCB 3D images
2026-08-25 Add Gerber directory
2026-08-25 Add BOM directory
